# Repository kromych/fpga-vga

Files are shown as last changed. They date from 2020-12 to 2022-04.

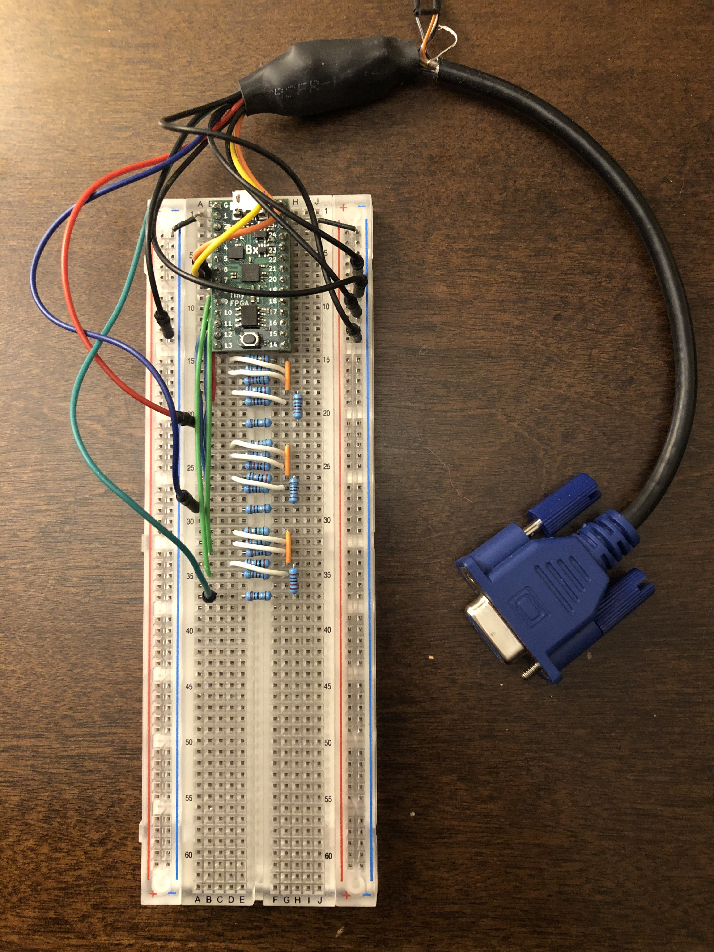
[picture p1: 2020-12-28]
img/bb_fpga.jpg

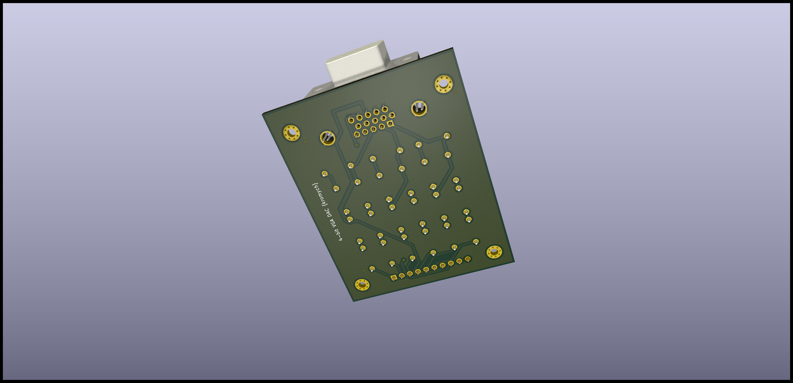
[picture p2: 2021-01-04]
kicad/KiCAD-VGA/pcb-bottom.png

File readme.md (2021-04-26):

## VGA and FPGAs

The blue, green, red componenets support 4 levels of brightness.

See [Simulations 01](./img/01.png), [Simulations 10](./img/10.png) and [Simulations 11](./img/11.png) 
for the details of the DAC implementation (modeled with [Electronic Circuit Simulator](http://www.falstad.com/circuit/circuitjs.html)).

Here are the TinyFPGA BX and the 4-bit DAC that on the [the breadboard](./img/bb_fpga.jpg) that are connected to a VGA input.
KiCAD schematic and the rendered pdf are under the [kicad](./kicad) directory.

## Installing tools

1. Yosys FPGA toolchain: https://github.com/YosysHQ/fpga-toolchain/releases
2. Tinyprog to program TinyFPGA BX: `pip install tinyprog`

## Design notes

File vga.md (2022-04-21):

## [DE-15 socket (graphic adapter output)](https://en.wikipedia.org/wiki/VGA_connector)

    VGA

        5(GND)    4        3(B)         2(G)         1(R)
           10(GND)      9        8(BGND)      7(GGND)    6(RGND)
        15        14(V)   13(H)         12           11

    Pin 1	RED	        Red video
    Pin 2	GREEN	    Green video
    Pin 3	BLUE	    Blue video
    Pin 4	ID2/RES	    Reserved since E-DDC, formerly monitor id. bit 2
    Pin 5	GND	Ground  (HSync)

    Pin 6	RGND	    Red ground
    Pin 7	GGND    	Green ground
    Pin 8	BGND    	Blue ground
    Pin 9	KEY/PWR	    +5 V DC (powers EDID EEPROM chip on some monitors), formerly key
    Pin 10	GND	        Ground (VSync, DDC)

    Pin 11	ID0/RES	    Reserved since E-DDC, formerly monitor id. bit 0
    Pin 12	ID1/SDA	    I2C data since DDC2, formerly monitor id. bit 1
    Pin 13	HSync	    Horizontal sync
    Pin 14	VSync	    Vertical sync
    Pin 15	ID3/SCL	    I2C clock since DDC2, formerly monitor id. bit 3

## [SVGA Signal 800 x 600 @ 60 Hz timing](http://www.tinyvga.com/vga-timing/800x600@60Hz)

### General timing

Signal              | Frequency
--------------------|---------------------
Screen refresh rate	| 60 Hz
Vertical refresh	| 37.878787878788 kHz
Pixel freq.	        | 40.0 MHz

### Horizontal timing (line)

_Polarity of horizontal sync pulse is positive_

Scanline part |	Pixels	| Time (µs)
--------------|---------|----------
Visible area  |	800	    | 20
Front porch	  | 40	    | 1
Sync pulse	  | 128	    | 3.2
Back porch	  | 88	    | 2.2
Whole line	  | 1056	| 26.4

### Vertical timing (frame)

_Polarity of vertical sync pulse is positive_

Frame part	  | Lines  | Time (ms)
--------------|--------|-----------
Visible area  | 600	   | 15.84
Front porch	  | 1	   | 0.0264
Sync pulse	  | 4	   | 0.1056
Back porch	  | 23	   | 0.6072
Whole frame	  | 628	   | 16.5792

## [VGA Signal 640 x 480 @ 73 Hz timing](http://www.tinyvga.com/vga-timing/640x480@73Hz)

Signal              | Frequency
--------------------|---------------------
Screen refresh rate	| 73 Hz
Vertical refresh	| 37.860576923077 kHz
Pixel freq.	        | 31.5 MHz

### Horizontal timing (line)

_Polarity of horizontal sync pulse is negative_

Scanline part |	Pixels	| Time (µs)
--------------|---------|----------
Visible area  | 640     | 20.31746031746
Front porch   |	24	    | 0.76190476190476
Sync pulse    |	40	    | 1.2698412698413
Back porch    | 128	    | 4.0634920634921
Whole line    | 832	    | 26.412698412698

### Vertical timing (frame)

_Polarity of vertical sync pulse is negative_

Frame part	  | Lines  | Time (ms)
--------------|--------|-----------
Visible area  | 480    | 12.678095238095
Front porch   | 9      | 0.23771428571429
Sync pulse    | 2      | 0.052825396825397
Back porch    | 29     | 0.76596825396825
Whole frame   | 520    | 13.734603174603

## [VGA Signal 640 x 480 @ 60 Hz timing](http://www.tinyvga.com/vga-timing/640x480@60Hz)

Signal              | Frequency
--------------------|---------------------
Screen refresh rate	| 60 Hz
Vertical refresh	| 31.46875 kHz
Pixel freq.	        | 25.175 MHz

### Horizontal timing (line)

_Polarity of horizontal sync pulse is negative._

Scanline part |	Pixels	| Time (µs)
--------------|---------|----------
Visible area  |	640     | 25.422045680238
Front porch	  | 16	    | 0.63555114200596
Sync pulse	  | 96	    | 3.8133068520357
Back porch	  | 48	    | 1.9066534260179
Whole line	  | 800	    | 31.777557100298

### Vertical timing (frame)

_Polarity of vertical sync pulse is negative._

Frame part	  | Lines  | Time (ms)
--------------|--------|-----------
Visible area  | 480	   | 15.253227408143
Front porch	  | 10	   | 0.31777557100298
Sync pulse	  | 2	   | 0.063555114200596
Back porch	  | 33	   | 1.0486593843098
Whole frame	  | 525	   | 16.683217477656

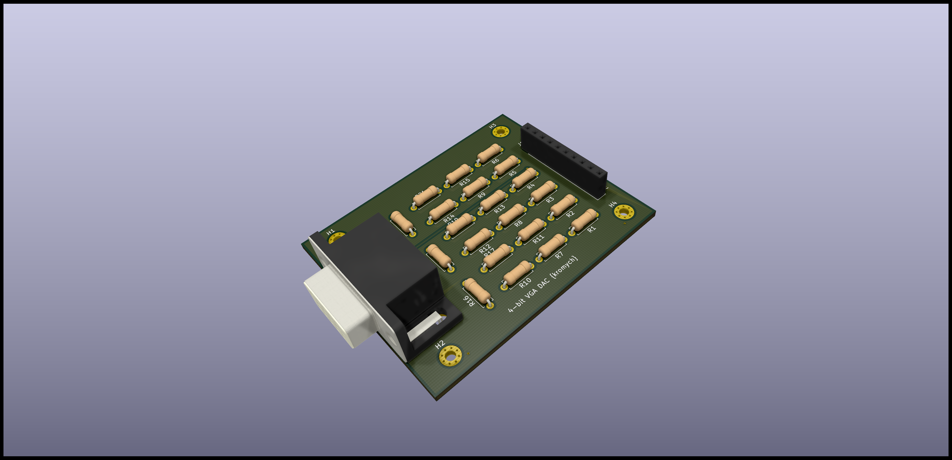
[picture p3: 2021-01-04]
kicad/KiCAD-VGA/pcb-top.png

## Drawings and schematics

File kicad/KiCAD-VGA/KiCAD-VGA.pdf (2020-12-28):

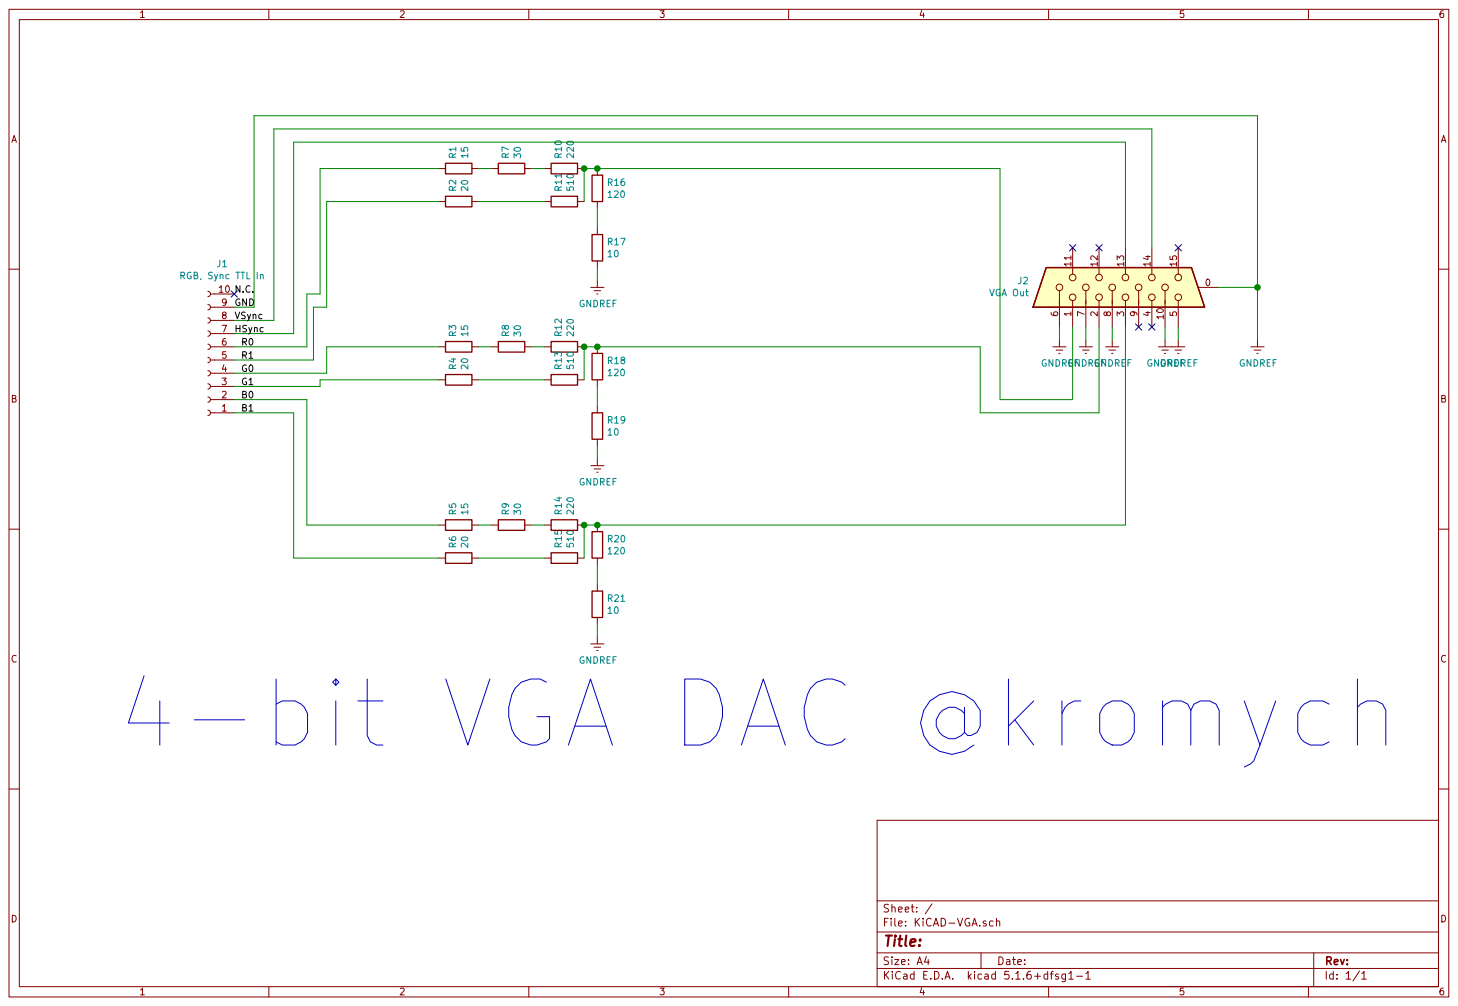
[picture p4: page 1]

VSync N.C. GND 4-bit VGA DAC @kromych

J1 RGB, Sync TTL In

Id: 1/1 Title: File: KiCAD-VGA.sch Sheet: / R21

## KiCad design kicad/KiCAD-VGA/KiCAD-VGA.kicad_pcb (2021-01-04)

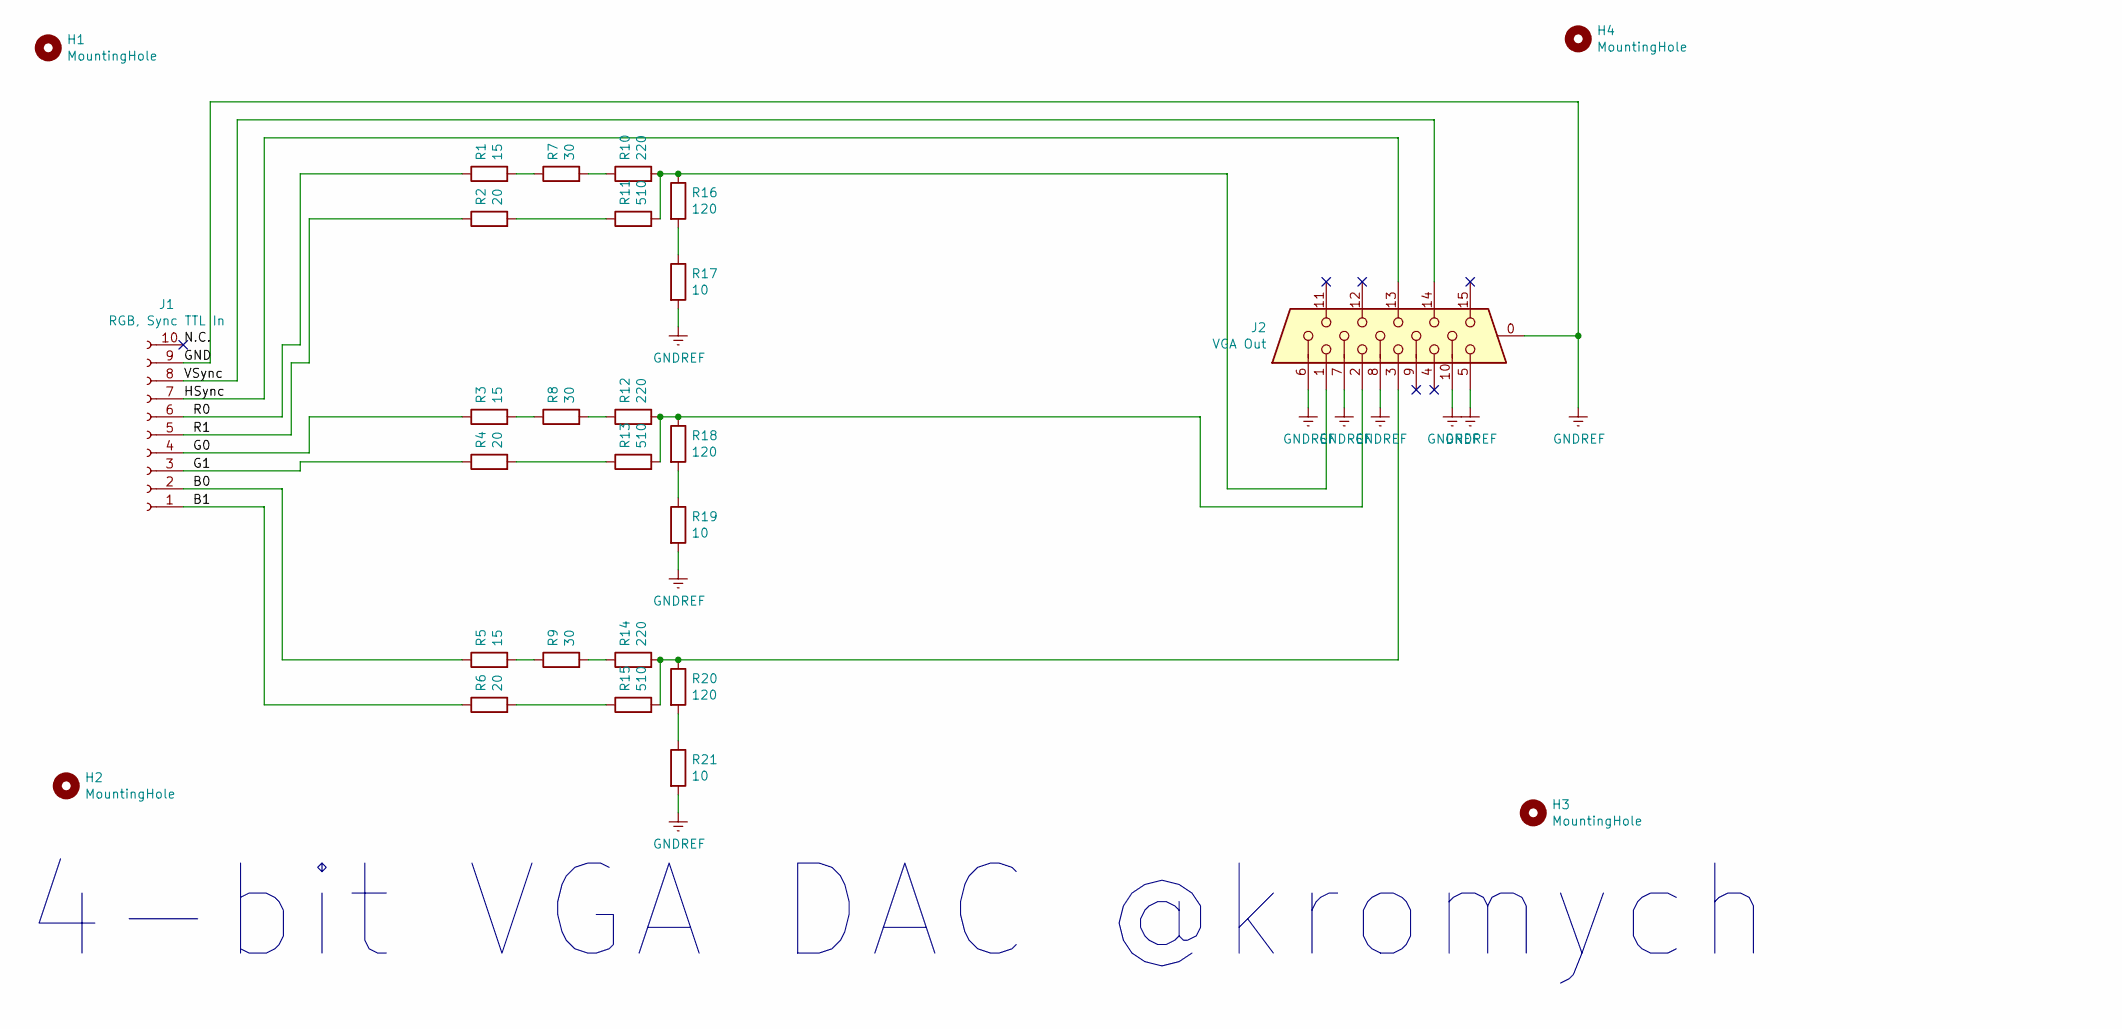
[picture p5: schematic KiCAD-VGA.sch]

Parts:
H1, H2, H3, H4: MountingHole; MountingHole_2.2mm_M2_Pad_Via
J1: RGB, Sync TTL In; PinSocket_1x10_P2.54mm_Vertical
J2: VGA Out; DSUB-15-HD_Female_Horizontal_P2.29x1.98mm_EdgePinOffset8.35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
R1, R3, R5: 15; R_Axial_DIN0207_L6.3mm_D2.5mm_P7.62mm_Horizontal
R2, R4, R6: 20; R_Axial_DIN0207_L6.3mm_D2.5mm_P7.62mm_Horizontal
R7, R8, R9: 30; R_Axial_DIN0207_L6.3mm_D2.5mm_P7.62mm_Horizontal
R10, R12, R14: 220; R_Axial_DIN0207_L6.3mm_D2.5mm_P7.62mm_Horizontal
R11, R13, R15: 510; R_Axial_DIN0207_L6.3mm_D2.5mm_P7.62mm_Horizontal
R16, R18, R20: 120; R_Axial_DIN0207_L6.3mm_D2.5mm_P7.62mm_Horizontal
R17, R19, R21: 10; R_Axial_DIN0207_L6.3mm_D2.5mm_P7.62mm_Horizontal

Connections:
/B0: J1.2, R5.1
/B1: J1.1, R6.1
/G0: J1.4, R3.1
/G1: J1.3, R4.1
/HSync: J1.7, J2.13
/R0: J1.6, R1.1
/R1: J1.5, R2.1
/VSync: J1.8, J2.14
GNDREF: J1.9, J2.0, J2.5, J2.6, J2.7, J2.8, J2.10, R17.2, R19.2, R21.2
unnamed: J2.1, R10.2, R11.2, R16.1
unnamed: J2.2, R12.2, R13.2, R18.1
unnamed: J2.3, R14.2, R15.2, R20.1
unnamed: R1.2, R7.1
unnamed: R3.2, R8.1
unnamed: R5.2, R9.1
unnamed: R7.2, R10.1
unnamed: R2.2, R11.1
unnamed: R8.2, R12.1
unnamed: R4.2, R13.1
unnamed: R9.2, R14.1
unnamed: R6.2, R15.1
unnamed: R16.2, R17.1
unnamed: R18.2, R19.1
unnamed: R20.2, R21.1

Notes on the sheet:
4-bit VGA DAC @kromych

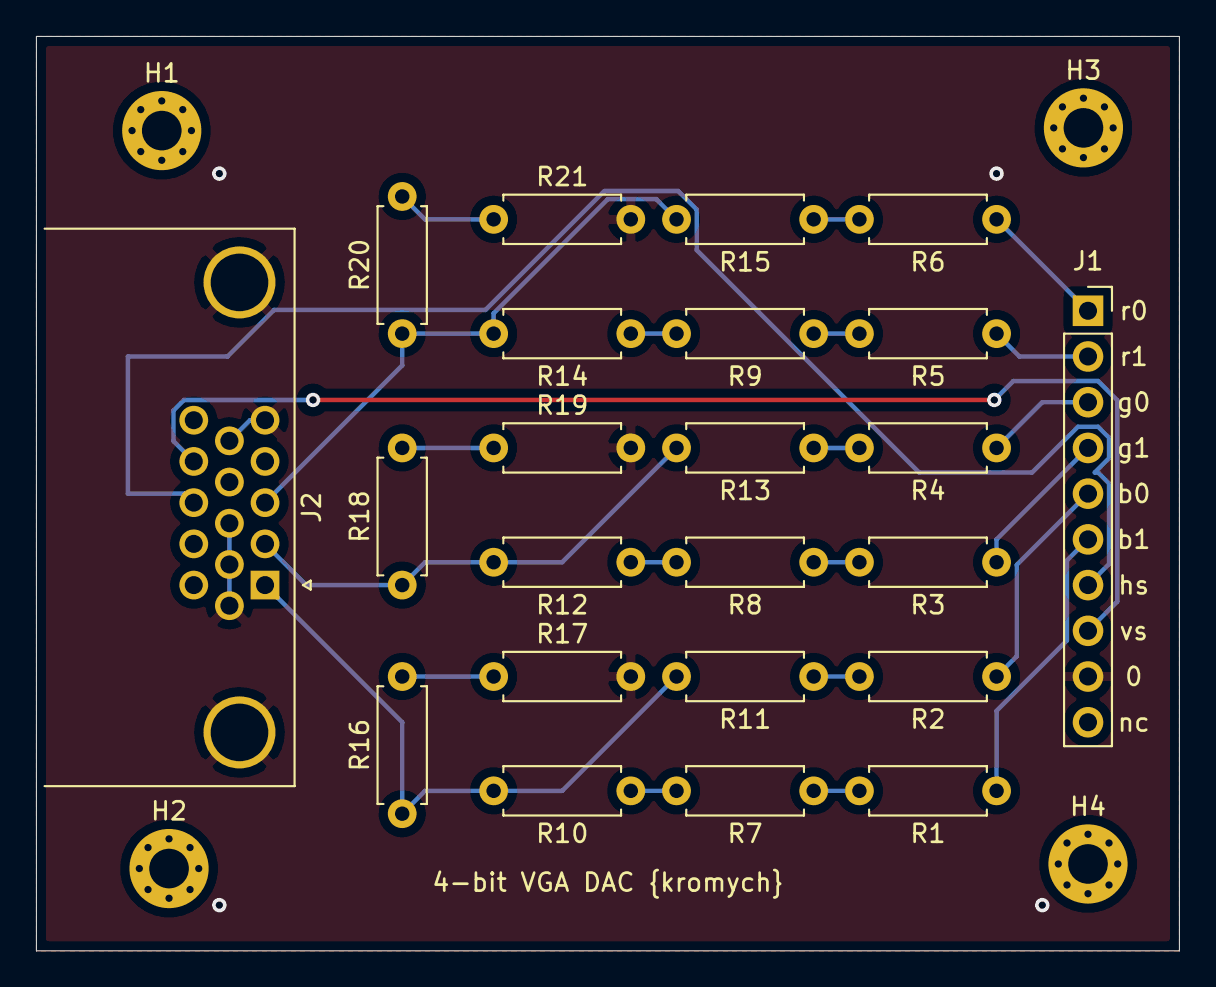
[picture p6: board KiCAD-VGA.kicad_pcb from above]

Board: 2 copper layers, 63.5 x 50.8 mm, 27 parts (0 on the bottom side), 24 nets.

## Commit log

2020-12-28 KiCAD schematics and the breadboard
    [KiCAD-VGA.sch]
2021-01-04 KiCAD project
    [KiCAD-VGA-B_Cu.gbr, KiCAD-VGA-B_Mask.gbr, KiCAD-VGA-B_Paste.gbr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]
2021-04-26 Better pins assignment to match the PCB
